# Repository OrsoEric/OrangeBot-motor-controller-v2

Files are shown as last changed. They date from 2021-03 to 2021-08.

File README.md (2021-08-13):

# OrangeBot-motor-controller-v2
Motor controller for OrangeBot Robot  
-VNH7040 Motor Driver  
-GD32VF103 Microcontroller  
-IG32E-05K Motor  

# Blog Entry  
https://orangebotpiwars2021.blogspot.com/2021/03/2021-03-20-orangebot-motor-controller.html

# Schematics  
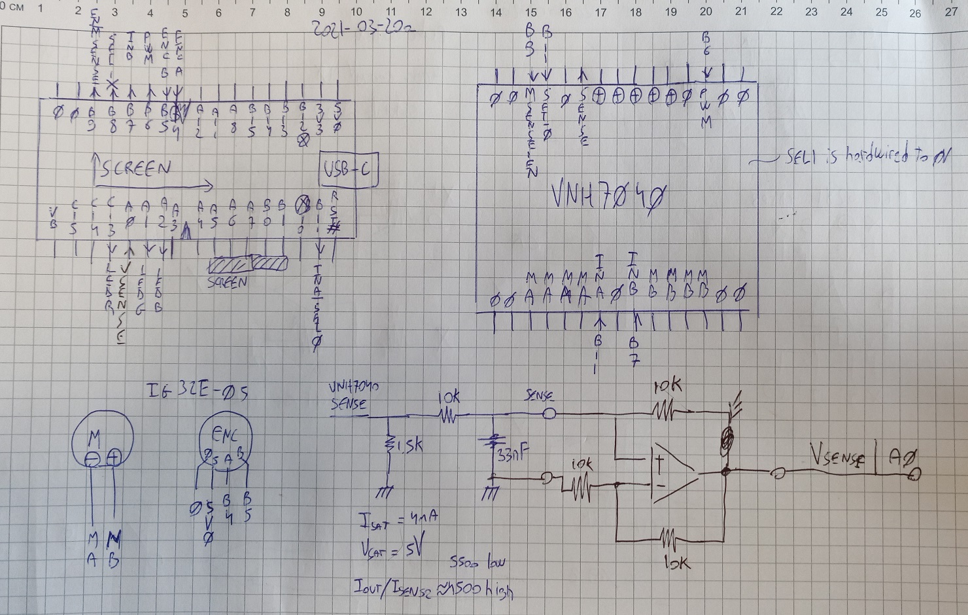
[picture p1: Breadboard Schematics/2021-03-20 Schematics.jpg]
Schematics
  

# Test bench  
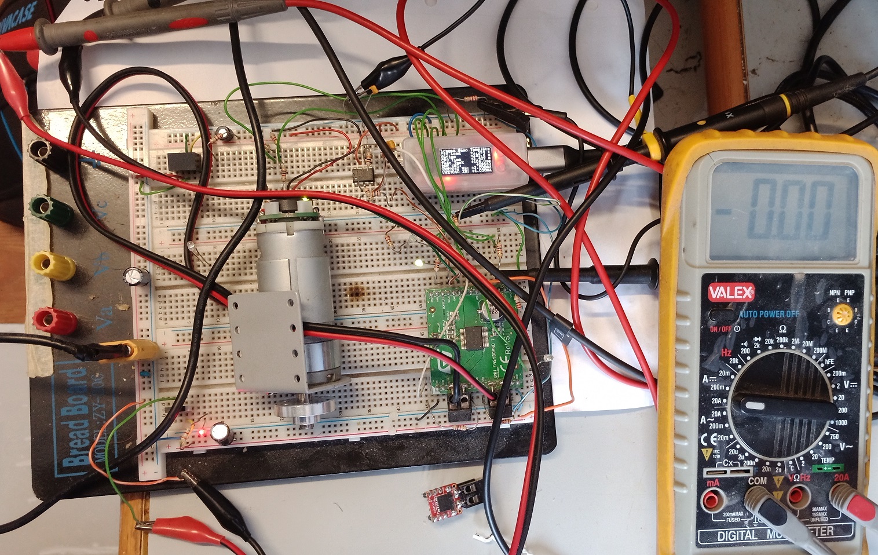
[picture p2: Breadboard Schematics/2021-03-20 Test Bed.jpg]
Test bench


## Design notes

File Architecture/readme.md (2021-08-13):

Features:  
- Use XT60 power connectors
- Daisy chain two power connectors
- RS485 communication bus using two 3.5mm Jack audio connectors
- Longan Nano GD32VF103 Risc-V 32b 108MHz microcontroller. Previous AT4809 lacked speed for the PIDs
- Quadrature Encoder with TTL levels
- LEDs for encoder activity and motor direction
- Overcurrent Protection, Reverse Voltage Protection and redundant VIN IIN monitor
 
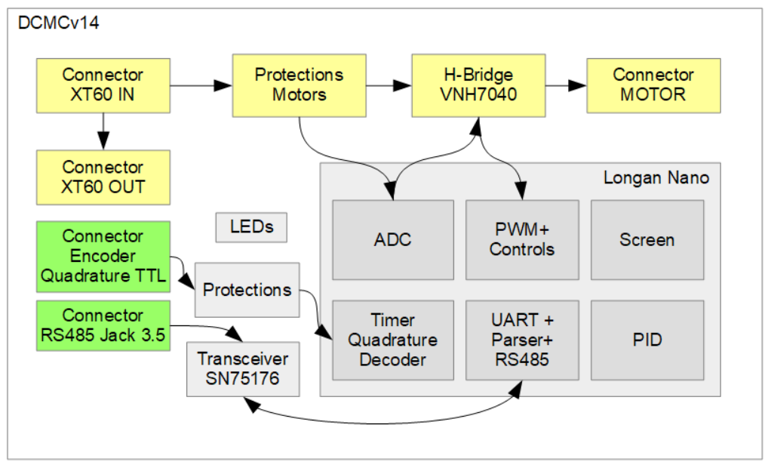
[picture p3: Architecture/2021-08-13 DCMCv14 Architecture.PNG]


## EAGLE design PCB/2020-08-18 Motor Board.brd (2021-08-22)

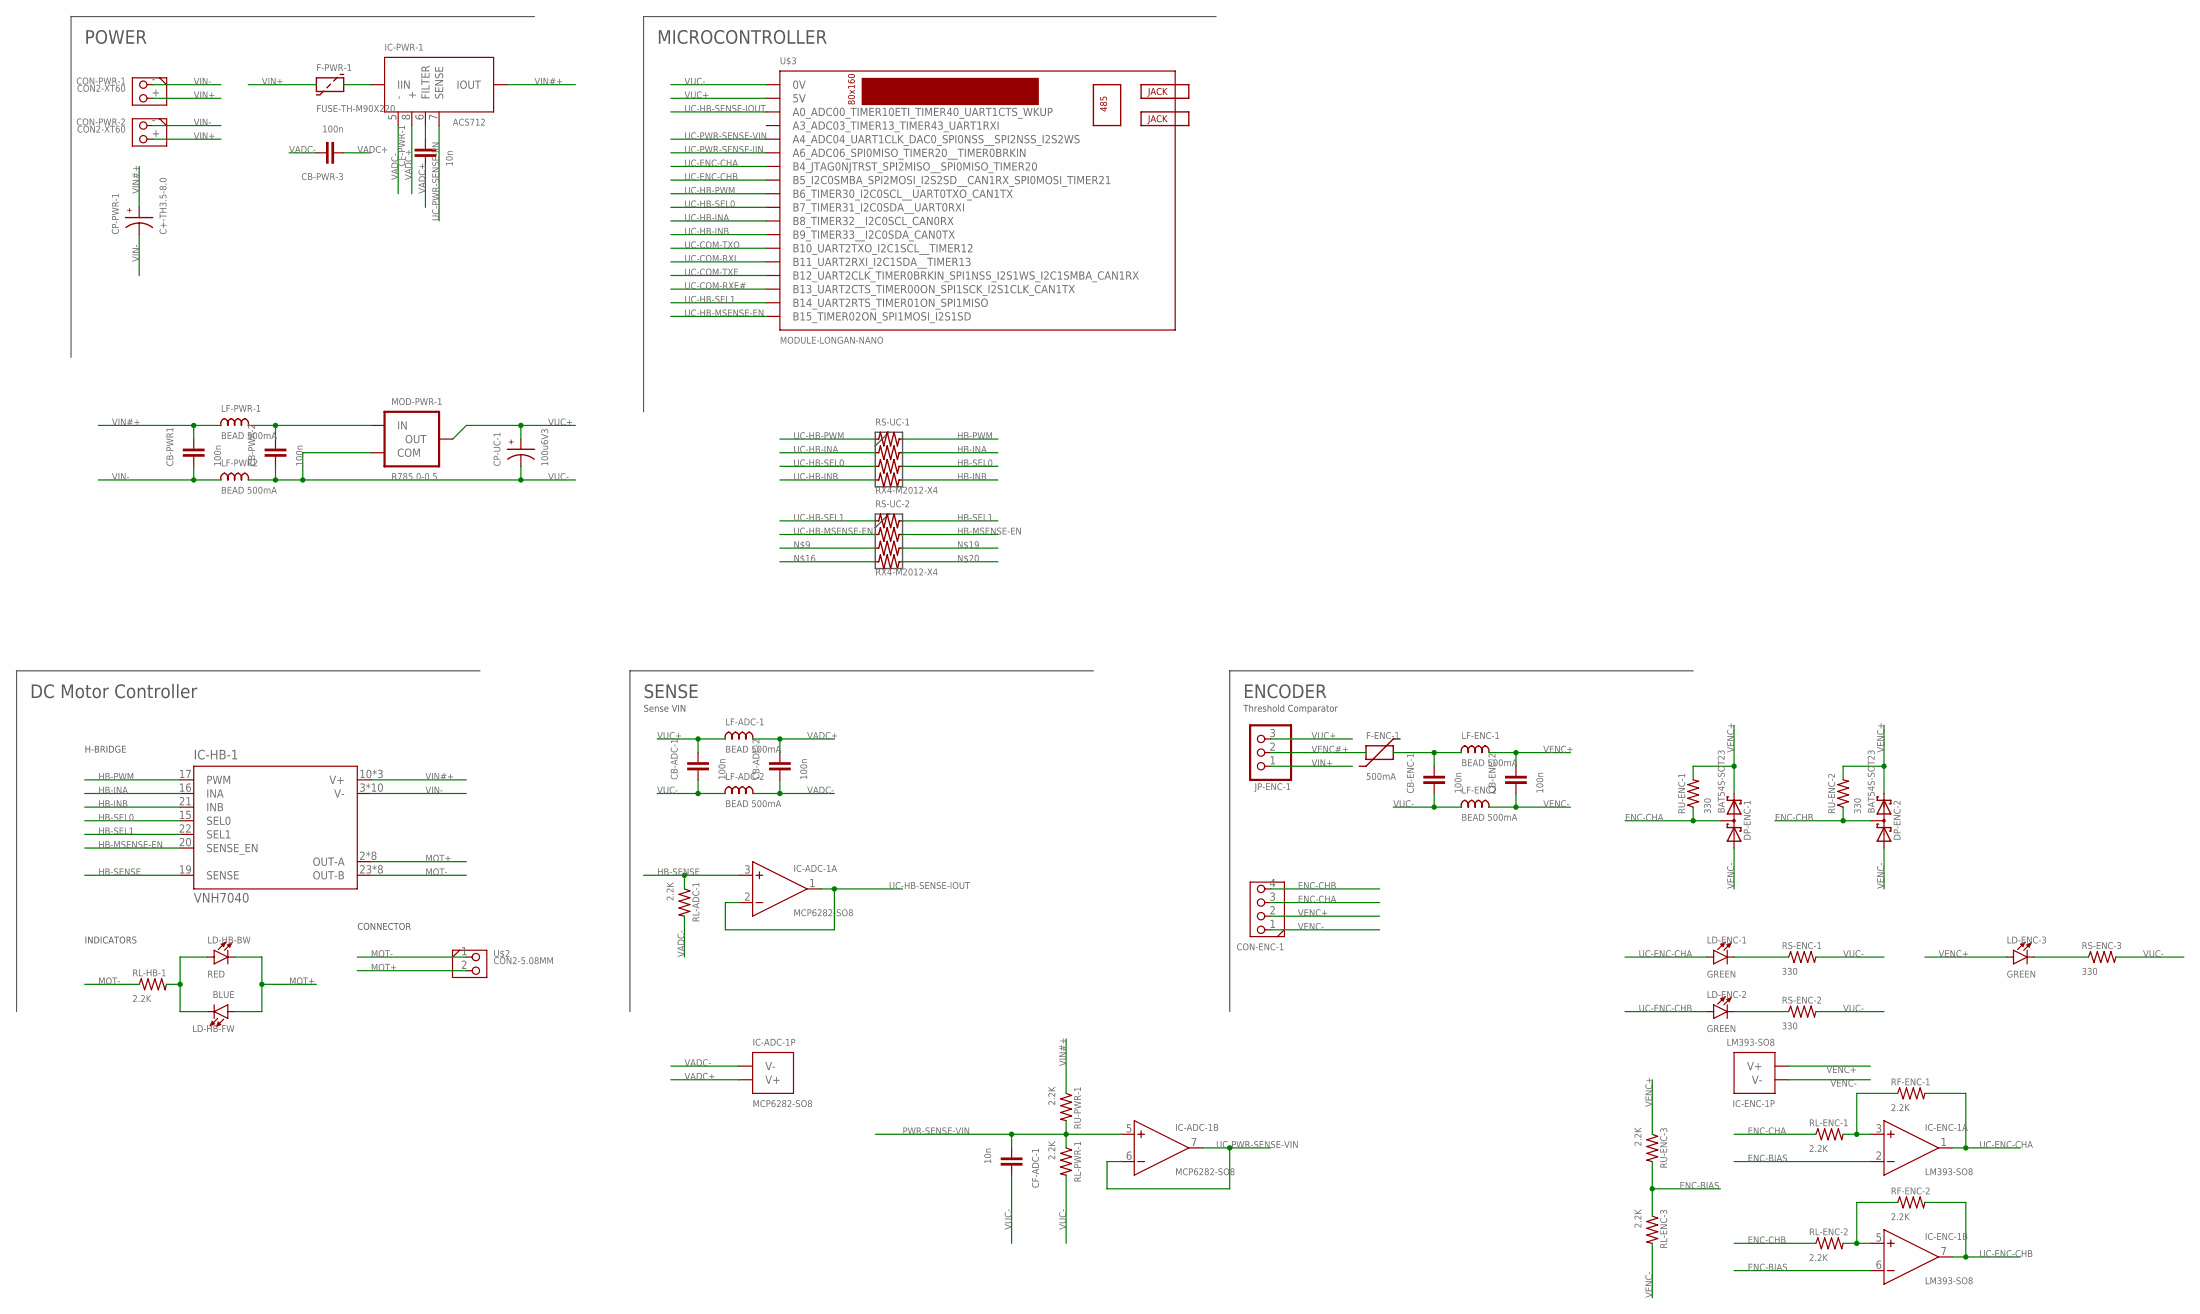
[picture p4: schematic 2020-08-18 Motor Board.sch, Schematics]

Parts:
CB-ADC-1, CB-ADC-2: 100n; SMD-M2012
CB-ENC-1, CB-ENC-2: 100n; SMD-M2012
CB-PWR1: 100n; SMD-M2012
CB-PWR-2, CB-PWR-3: 100n; SMD-M2012
CF-ADC-1: 10n; SMD-M2012
CF-PWR-1: 10n; SMD-M2012
CON-ENC-1: CON4
CON-PWR-1, CON-PWR-2: CON2-XT60; AMASS_XT60-M
CP-PWR-1: C+-TH3.5-8.0; TH-BARREL-3M5-8M0
CP-UC-1: 100u6V3; TH-BARREL-2M54-6M0
DP-ENC-1, DP-ENC-2: BAT54S-SOT23; SOT23
F-ENC-1: 500mA; SMD-M2012
F-PWR-1: FUSE-TH-M90X220; TH-BOX-MM9X22
IC-ADC-1: MCP6282-SO8; SO8
IC-ENC-1: LM393-SO8; SO8
IC-HB-1: VNH7040; SSO-36-TP
IC-PWR-1: ACS712; SO8
JP-ENC-1: PINHD-1X3; 1X03
LD-ENC-1, LD-ENC-2, LD-ENC-3: GREEN; SMD-M2012-POL
LD-HB-BW: RED; SMD-M2012-POL
LD-HB-FW: BLUE; SMD-M2012-POL
LF-ADC-1, LF-ADC-2: BEAD 500mA; SMD-M2012
LF-ENC2: BEAD 500mA; SMD-M2012
LF-ENC-1: BEAD 500mA; SMD-M2012
LF-PWR2: BEAD 500mA; SMD-M2012
LF-PWR-1: BEAD 500mA; SMD-M2012
MOD-PWR-1: R785.0-0.5; CUSTOM_SIP3_PIN
RF-ENC-1, RF-ENC-2: 2.2K; SMD-M2012
RL-ADC-1: 2.2K; SMD-M2012
RL-ENC-1, RL-ENC-2, RL-ENC-3: 2.2K; SMD-M2012
RL-HB-1: 2.2K; SMD-M2012
RL-PWR-1: 2.2K; SMD-M2012
RS-ENC-1, RS-ENC-2, RS-ENC-3: 330; SMD-M2012
RS-UC-1, RS-UC-2: RX4-M2012-X4; SMD-M2012-X4
RU-ENC-1, RU-ENC-2: 330; SMD-M2012
RU-ENC-3: 2.2K; SMD-M2012
RU-PWR-1: 2.2K; SMD-M2012
U$2: CON2-5.08MM; CON2-508
U$3: MODULE-LONGAN-NANO

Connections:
ENC-BIAS: IC-ENC-1.2 (-IN), IC-ENC-1.6 (-IN), RL-ENC-3.1, RU-ENC-3.2
ENC-CHA: CON-ENC-1.3, DP-ENC-1.3 (C1A2), RL-ENC-1.1, RU-ENC-1.1
ENC-CHB: CON-ENC-1.4, DP-ENC-2.3 (C1A2), RL-ENC-2.1, RU-ENC-2.1
HB-INA: IC-HB-1.16 (INA), RS-UC-1.2B
HB-INB: IC-HB-1.21 (INB), RS-UC-1.4B
HB-MSENSE-EN: IC-HB-1.20 (SENSE_EN), RS-UC-2.2B
HB-PWM: IC-HB-1.17 (PWM), RS-UC-1.1B
HB-SEL0: IC-HB-1.15 (SEL0), RS-UC-1.3B
HB-SEL1: IC-HB-1.22 (SEL1), RS-UC-2.1B
HB-SENSE: IC-ADC-1.3 (+IN), IC-HB-1.19 (SENSE), RL-ADC-1.1
MOT+: IC-HB-1.2 (OUT-A), IC-HB-1.8 (OUT-A), IC-HB-1.9 (OUT-A), IC-HB-1.11 (OUT-A), IC-HB-1.12 (OUT-A), IC-HB-1.13 (OUT-A), IC-HB-1.14 (OUT-A), IC-HB-1.PAD2 (OUT-A), LD-HB-BW.-, LD-HB-FW.+, U$2.2
MOT-: IC-HB-1.23 (OUT-B), IC-HB-1.24 (OUT-B), IC-HB-1.25 (OUT-B), IC-HB-1.26 (OUT-B), IC-HB-1.28 (OUT-B), IC-HB-1.29 (OUT-B), IC-HB-1.35 (OUT-B), IC-HB-1.PAD3 (OUT-B), RL-HB-1.1, U$2.1
unnamed: LD-HB-BW.+, LD-HB-FW.-, RL-HB-1.2
unnamed: CF-PWR-1.2, IC-PWR-1.6 (FILTER)
unnamed: F-PWR-1.2, IC-PWR-1.1 (IIN), IC-PWR-1.2 (IIN)
unnamed: IC-ENC-1.3 (+IN), RF-ENC-1.1, RL-ENC-1.2
unnamed: LD-ENC-2.-, RS-ENC-2.1
unnamed: IC-ENC-1.5 (+IN), RF-ENC-2.1, RL-ENC-2.2
unnamed: LD-ENC-1.-, RS-ENC-1.1
unnamed: CB-PWR-2.2, LF-PWR-1.2, MOD-PWR-1.VIN (IN)
unnamed: CB-ENC-1.2, F-ENC-1.2, LF-ENC-1.1
unnamed: LD-ENC-3.-, RS-ENC-3.1
PWR-SENSE-VIN: CF-ADC-1.1, IC-ADC-1.5 (+IN), RL-PWR-1.1, RU-PWR-1.2
UC-COM-RXE#: U$3.B13 (B13_UART2CTS_TIMER00ON_SPI1SCK_I2S1CLK_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)
UC-COM-RXI: U$3.B11 (B11_UART2RXI_I2C1SDA__TIMER13)
UC-COM-TXE: U$3.B12 (B12_UART2CLK_TIMER0BRKIN_SPI1NSS_I2S1WS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)
UC-COM-TXO: U$3.B10 (B10_UART2TXO_I2C1SCL__TIMER12)
UC-ENC-CHA: IC-ENC-1.1 (OUT), LD-ENC-1.+, RF-ENC-1.2, U$3.B4 (B4_JTAG0NJTRST_SPI2MISO__SPI0MISO_TIMER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)
UC-ENC-CHB: IC-ENC-1.7 (OUT), LD-ENC-2.+, RF-ENC-2.2, U$3.B5 (B5_I2C0SMBA_SPI2MOSI_I2S2SD__CAN1RX_SPI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)
UC-HB-INA: RS-UC-1.2A, U$3.B8 (B8_TIMER32__I2C0SCL_CAN0RX)
UC-HB-INB: RS-UC-1.4A, U$3.B9 (B9_TIMER33__I2C0SDA_CAN0TX)
UC-HB-MSENSE-EN: RS-UC-2.2A, U$3.B15 (B15_TIMER02ON_SPI1MOSI_I2S1SD)
UC-HB-PWM: RS-UC-1.1A, U$3.B6 (B6_TIMER30_I2C0SCL__UART0TXO_CAN1TX)
UC-HB-SEL0: RS-UC-1.3A, U$3.B7 (B7_TIMER31_I2C0SDA__UART0RXI)
UC-HB-SEL1: RS-UC-2.1A, U$3.B14 (B14_UART2RTS_TIMER01ON_SPI1MISO)
UC-HB-SENSE-IOUT: IC-ADC-1.1 (OUT), IC-ADC-1.2 (-IN), U$3.A0 (A0_ADC00_TIMER10ETI_TIMER40_UART1CTS_WK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)
UC-PWR-SENSE-IIN: IC-PWR-1.7 (SENSE), U$3.A6 (A6_ADC06_SPI0MISO_TIMER20__TIMER0BRKIN)
UC-PWR-SENSE-VIN: IC-ADC-1.6 (-IN), IC-ADC-1.7 (OUT), U$3.A4 (A4_ADC04_UART1CLK_DAC0_SPI0NSS__SPI2NSS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)
VADC+: CB-ADC-2.2, CB-PWR-3.1, CF-PWR-1.1, IC-ADC-1.8 (V+), IC-PWR-1.8 (+), LF-ADC-1.2
VADC-: CB-ADC-2.1, CB-PWR-3.2, IC-ADC-1.4 (V-), IC-PWR-1.5 (-), LF-ADC-2.2, RL-ADC-1.2
VENC#+: F-ENC-1.1, JP-ENC-1.2
VENC+: CB-ENC-2.2, CON-ENC-1.2, DP-ENC-1.2 (C2), DP-ENC-2.2 (C2), IC-ENC-1.8 (V+), LD-ENC-3.+, LF-ENC-1.2, RU-ENC-1.2, RU-ENC-2.2, RU-ENC-3.1
VENC-: CB-ENC-2.1, CON-ENC-1.1, DP-ENC-1.1 (A1), DP-ENC-2.1 (A1), IC-ENC-1.4 (V-), LF-ENC2.2, RL-ENC-3.2
VIN#+: CB-PWR1.2, CP-PWR-1.+, IC-HB-1.10 (V+), IC-HB-1.27 (V+), IC-HB-1.PAD1 (V+), IC-PWR-1.3 (IOUT), IC-PWR-1.4 (IOUT), LF-PWR-1.1, RU-PWR-1.1
VIN+: CON-PWR-1.+ (2), CON-PWR-2.+ (2), F-PWR-1.1, JP-ENC-1.1
VIN-: CB-PWR1.1, CON-PWR-1.- (1), CON-PWR-2.- (1), CP-PWR-1.-, IC-HB-1.3 (V-), IC-HB-1.4 (V-), IC-HB-1.5 (V-), IC-HB-1.6 (V-), IC-HB-1.7 (V-), IC-HB-1.30 (V-), IC-HB-1.31 (V-), IC-HB-1.32 (V-), IC-HB-1.33 (V-), IC-HB-1.34 (V-), LF-PWR2.1
VUC+: CB-ADC-1.2, CP-UC-1.+, JP-ENC-1.3, LF-ADC-1.1, MOD-PWR-1.OUT, U$3.5V
VUC-: CB-ADC-1.1, CB-ENC-1.1, CB-PWR-2.1, CF-ADC-1.2, CP-UC-1.-, LF-ADC-2.1, LF-ENC2.1, LF-PWR2.2, MOD-PWR-1.COM, RL-PWR-1.2, RS-ENC-1.2, RS-ENC-2.2, RS-ENC-3.2, U$3.0V

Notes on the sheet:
POWER
MICROCONTROLLER
DC Motor Controller
ENCODER
SENSE
H-BRIDGE
INDICATORS
CONNECTOR
Threshold Comparator
Sense VIN

Board: 2 copper layers, 54 parts (16 on the bottom side), 44 nets, no tracks yet.

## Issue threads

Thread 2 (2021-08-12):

DCMC - Schematics - Breadboard

OrsoEric, 2021-08-12:
VNH7040 and Longan Nano have been tested on a breadboard.

- IG32-05 DC Motor with encoder
- VNH7040 Evaluation Board
- Longan Nano GD32VF103 board with screen and USB-C programmer

OrsoEric, 2021-08-12:
Schematics
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

Closed 2021-08-12.

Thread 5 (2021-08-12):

DCMC - Firmware

OrsoEric, 2021-08-12:
Firmware for the DCMC (DC Motor Controller)

Breadboard Tests
- [ ] Longan Nano LCD
- [ ] Longan Nano Task Scheduler
- [ ] Longan nano ADC
- [ ] VNH7040 Open Loop PWM Ramp
- [ ] IG32-05 Encoder acquisition
- [ ] VNH7040 Closed Loop Position

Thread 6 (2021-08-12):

DCMC - PCB

OrsoEric, 2021-08-12:
Design of the PCB Printed Circuit Board for the DC Motor Controller v14

- [ ] Net Classes
- [ ] Design Rules
- [ ] Placement
- [ ] Routing
- [ ] Gerber

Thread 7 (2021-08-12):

DCMC - PCB - Placement

OrsoEric, 2021-08-12:
Define board size and derive initial placement of components on the board.

OrsoEric, 2021-08-12:
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

OrsoEric, 2021-08-22:
Specifications:
- Board Size: 60mm x 60mm
- Vertical mounting of Longan nano via daughter board. Includes 485 communications
- Square holes 4.5mm in a 50x50mm grid
- Vertical stacking of board by strategically soldering the XT60 in a daisy chain

Initial placement and initial result of auto-router

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

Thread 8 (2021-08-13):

DCMC - Change Repository Structure

OrsoEric, 2021-08-13:
This repository was originally meant to store the firmware for the breadboard test for the new PiWars motor controller.

Scope of the project has increased to make an high power DC motor controller compatible with the OrangeHat.

OrsoEric, 2021-08-13:
Updated repository structure to include breadboard and PCB sections.

Closed 2021-08-13.

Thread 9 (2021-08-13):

DCMC - Architecture

OrsoEric, 2021-08-13:
Architecture and features for the DCMC DC Motor Controller.

OrsoEric, 2021-08-13:
Features:
- Use XT60 power connectors
- Daisy chain two power connectors
- RS485 communication bus using two 3.5mm Jack audio connectors
- Longan Nano GD32VF103 Risc-V 32b 108MHz microcontroller. Previous AT4809 lacked speed for the PIDs
- Quadrature Encoder with TTL levels
- LEDs for encoder activity and motor direction
- Overcurrent Protection, Reverse Voltage Protection and redundant VIN IIN monitor

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

Closed 2021-08-13.

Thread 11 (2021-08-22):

DCMC - Schematics - Power

OrsoEric, 2021-08-22:
Specifications:
- Two XT60 power connectors to allow daisy chain both with cables and vertically.
- Buck module to generate 5V for the logic
- Extensive power filters
- Independent measure of IIN using a current sensor. It is redundant since VNH7040 has integrated current sensing. It's meant for validation.

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

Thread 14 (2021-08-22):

DCMC - Schematics - Encoder

OrsoEric, 2021-08-22:
Specifications:
- Quadrature encoder, single ended
- Optional pull-up resistors for open drain encoders
- Jumper to select encoder supply between 5V/VIN
- PTC to protect encoder supply from short circuit on encoder
- High speed rail to rail comparators with hysteresis on channels
- Power filter

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

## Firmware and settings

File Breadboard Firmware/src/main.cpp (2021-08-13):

/****************************************************************************
**	OrangeBot Project
*****************************************************************************
**        /
**       /
**      /
** ______ \
**         \
**          \
*****************************************************************************
**	Quadrature Encoder
*****************************************************************************
**  Activate Timer 2 in quadrature mode
**  Count a quadrature encoder connected to PB4 and PB5
**  Display the encoder count on screen
**  Repository:
**  https://github.com/OrsoEric/OrangeBot-motor-controller-v2
**      2021-03-20
**  Remove uC temperature. Add ADC CH0, motor Vsense
****************************************************************************/

/****************************************************************************
**	INCLUDES
****************************************************************************/

//C++ std random number generators
#include <random>
//Longan Nano HAL
#include <gd32vf103.h>
//LED class
#include "longan_nano_led.hpp"
//Time class
#include "longan_nano_chrono.hpp"
//Scheduler class
#include "longan_nano_scheduler.hpp"
//Higher level abstraction layer to base Display Class. Provides character sprites and print methods with color
#include "longan_nano_screen.hpp"
//Driver for the VNH7040 H-Bridge
#include "longan_nano_vnh7040.hpp"
//Old 16b PID controller
#include "pid_s16.h"

/****************************************************************************
**	NAMESPACES
****************************************************************************/

/****************************************************************************
**	DEFINES
****************************************************************************/

//forever
#define EVER (;;)

/****************************************************************************
**	MACROS
****************************************************************************/

/****************************************************************************
**	ENUM
****************************************************************************/

//Configurations
typedef enum _Config
{
    SCHEDULER_UNIT      = Longan_nano::Chrono::Unit::microseconds,
    //Microseconds between calls of the screen update method. User decides how much CPU to allocate to the screen by tuning this time.
    //Longer time will mean fewer sprites rendered per second, but no matter what, the screen class will not crash as only the most recent sprite is drawn
    SCREEN_US           = 100,
    //HMI UPDATE
    HMI_US              = 100000,
    //Microseconds between led toggles
    RED_LED_BLINK_US    = 250000,
    //Microseconds between paint of colored square
    PAINT_TASK_US       = 300000,

    VNH7040_TASK_US     = 1000,

    SCREEN_TASK_INDEX   = 0,
    HMI_TASK_INDEX      = 1,
    RED_LED_TASK_INDEX  = 2,
    PAINT_TASK_INDEX    = 3,
    VNH7040_TASK_INDEX  = 4,
    PAINT_START_HEIGHT  = 6,
} Config;

/****************************************************************************
**	STRUCT
****************************************************************************/

typedef struct _Scheduler
{
    bool f_screen       : 1;
    bool f_demo         : 1;
    bool f_overrun      : 1;
} Scheduler;

/****************************************************************************
**  PROTOTYPES
****************************************************************************/

//Initialize
extern bool init_enc( void );

extern bool init_adc_temp(void);

extern bool test_vnh7040( void );

/****************************************************************************
**  GLOBAL VARIABILES
****************************************************************************/

volatile bool g_rtc_flag = false;

//C++ Standard Random Number Generator
std::default_random_engine g_rng_engine;
std::uniform_int_distribution<uint8_t> g_rng_color( 0, Longan_nano::Screen::Config::PALETTE_SIZE -1 );
//Scheduler for the tasks
Scheduler g_scheduler = { 0 };
//VNH7040 Motor controller
Longan_nano::VNH7040 g_vnh7040;
//PID controller
int_fast32_t gs32_vnh7040_command;
int_fast32_t gs32_encoder_feedback;
bool gu1_pid_error = false;

//Debug: use old controller for sanity check
Orangebot::Pid_s16 gcl_pid16_controller;

/****************************************************************************
**	FUNCTIONS
****************************************************************************/

/****************************************************************************
**	@brief main
**	main | void
****************************************************************************/
//! @return int |
//! @details Entry point of program
/***************************************************************************/

int main( void )
{
    //----------------------------------------------------------------
    //	VARS
    //----------------------------------------------------------------

    //Task scheduler. Initialize with fast tick for the screen driver
    Longan_nano::Scheduler g_scheduler = Longan_nano::Scheduler( Config::SCREEN_US, (Longan_nano::Chrono::Unit)Config::SCHEDULER_UNIT );
    //Display Driver
    Longan_nano::Screen g_screen;

    bool f_ret = false;

    //----------------------------------------------------------------
    //	INIT
    //----------------------------------------------------------------

    //Initialize LEDs
    Longan_nano::Leds::init();
    Longan_nano::Leds::set_color( Longan_nano::Leds::Color::BLACK );
    //Initialize scheduler
    f_ret |= g_scheduler.set_prescaler( Config::HMI_TASK_INDEX, Config::HMI_US /Config::SCREEN_US );
    f_ret |= g_scheduler.set_prescaler( Config::RED_LED_TASK_INDEX, Config::RED_LED_BLINK_US /Config::SCREEN_US );
    //f_ret |= g_scheduler.set_prescaler( Config::PAINT_TASK_INDEX, Config::PAINT_TASK_US /Config::SCREEN_US );
    f_ret |= g_scheduler.set_prescaler( Config::VNH7040_TASK_INDEX, Config::VNH7040_TASK_US /Config::SCREEN_US );
    //Initialize the Display
    g_screen.init();

    //Initialize Timer2 as Quadrature encoder decoder
    init_enc();
	//Initialize ADC
	init_adc_temp();
    //Initialize VNH7040
    f_ret = g_vnh7040.init();
    //PID Initialization
    
   	gcl_pid16_controller.gain_kp() = +12800;
	gcl_pid16_controller.gain_ki() = +100;
	gcl_pid16_controller.gain_kd() = +0;
	gcl_pid16_controller.set_limit_cmd( -10000, +10000 );
    
    //Error state
    //gu1_pid_error = !gcl_pid_controller.is_ready();
    gu1_pid_error = false;

    //----------------------------------------------------------------
    //	ERROR HANDLER
    //----------------------------------------------------------------

    if (f_ret == true)
    {
        g_screen.clear( Longan_nano::Screen::Color::RED );
        g_screen.print( 0, 0, "ERR: Init Failed", Longan_nano::Screen::Color::RED, Longan_nano::Screen::Color::BLACK );
        for EVER
        {
            //Update the screen
            g_screen.update();
        }
    }

    uint8_t task_index;

    //----------------------------------------------------------------
    //	BODY
    //----------------------------------------------------------------

    for EVER
    {
        //----------------------------------------------------------------
        //  Scheduler
        //----------------------------------------------------------------
        //  Hardwired scheduler to release tasks
        //  Thanks to the Longan Nano SysTick timer there is no need to use peripherals for timekeeping

        //Run the scheduler
        int8_t num_tasks = g_scheduler.update();
        //if: scheduling error
        if (num_tasks < 0)
        {
            g_screen.clear( Longan_nano::Screen::Color::LRED );
            g_screen.print( 0, 0, "ERR: Scheduler Error", Longan_nano::Screen::Color::LRED, Longan_nano::Screen::Color::BLACK );
        }

        //----------------------------------------------------------------
        //  Screen Driver
        //----------------------------------------------------------------

        //Set task index
        task_index = Config::SCREEN_TASK_INDEX;
        //if: task is scheduled for execution
        if (g_scheduler.is_task_scheduled( task_index ) == true)
        {
            //Task is running
            g_scheduler.run( task_index );
            
            //Update the screen
            g_screen.update();
            
            //Task is done running
            g_scheduler.done( task_index );
        }

        //----------------------------------------------------------------
        //  HMI Update
        //----------------------------------------------------------------

        //Set task index
        task_index = Config::HMI_TASK_INDEX;
        //if: task is scheduled for execution
        if (g_scheduler.is_task_scheduled( task_index )  == true)
        {
            //Task is running
            g_scheduler.run( task_index );
            
            //----------------------------------------------------------------
            //  Header
            //----------------------------------------------------------------
    
            g_screen.print( 0, 0, "Longan Nano Template" );

            //----------------------------------------------------------------
            //  CPU Load
            //----------------------------------------------------------------
    
            /*
            g_screen.print( 1, 0, "CPU Load" );
            //Use top of 100000 to get enough decimals. To print in the right format witn 100000->100.0% ENG exponent is -3 (TOP 100000 /10^ENG_EXP -3 = 100)
            g_screen.set_format( 8, Longan_nano::Screen::Format_align::ADJ_RIGHT, Longan_nano::Screen::Format_format::ENG, -3 );
            //Get CPU load with 100000 = 100.0%
            int cpu_load = g_scheduler.get_cpu_load( 100000 );
            g_screen.print( 1, 18, cpu_load );
            g_screen.print( 1, 19, '%' );
            */
            
            //----------------------------------------------------------------
            //  Uptime and CPU Time
            //----------------------------------------------------------------
            int tmp;
            //Since the time is measured in millisecond exponent is 10^-3
            g_screen.set_format( 8, Longan_nano::Screen::Format_align::ADJ_RIGHT, Longan_nano::Screen::Format_format::ENG, -3 );
            
            if (gu1_pid_error == true)
            {
                g_screen.print( 2, 0, "PID ERROR" );
            }
            else
            {
                g_screen.print( 2, 0, "PID OK" );
            }
            /*
            g_screen.print( 2, 0, "Uptime" );
            tmp = g_scheduler.get_uptime( Longan_nano::Chrono::Unit::milliseconds );
            g_screen.print( 2, 18, tmp );
            g_screen.print( 2, 19, 's' );
            */
            
            /*
            g_screen.print( 3, 0, "CPU Time" );
            tmp = g_scheduler.get_cpu_time( Longan_nano::Chrono::Unit::milliseconds );
            g_screen.print( 3, 18, tmp );
            g_screen.print( 3, 19, 's' );
            */

            g_screen.set_format( 8, Longan_nano::Screen::Format_align::ADJ_RIGHT, Longan_nano::Screen::Format_format::NUM );
            g_screen.print( 3, 0, "VNH7040" );
            g_screen.print( 3, 19, gs32_vnh7040_command );

            //----------------------------------------------------------------
            //  Execution time of fast task
            //---------------------------------------------------------------- 

            g_screen.print( 4, 0, "Fast Task" );
            tmp = g_scheduler.get_fast_task_avg_time();
            //The scheduler is using microseconds as time unit in the configuration
            g_screen.set_format( 8, Longan_nano::Screen::Format_align::ADJ_RIGHT, Longan_nano::Screen::Format_format::ENG, -6 );
            g_screen.print( 4, 18, tmp );
            g_screen.print( 4, 19, 's' );            

            //----------------------------------------------------------------
            //  ENC Profiling
            //---------------------------------------------------------------- 
            
            //Get the count of the timer
            tmp = gs32_encoder_feedback;
            g_screen.set_format( 8, Longan_nano::Screen::Format_align::ADJ_RIGHT, Longan_nano::Screen::Format_format::NUM );
            g_screen.print( 5, 0, "ENC CNT:" );
            g_screen.print( 5, 19, tmp );

            //----------------------------------------------------------------
            //  ADC Acquisition
            //---------------------------------------------------------------- 
	
            //Fetch and process temperature in celsius m[°c] 
            //int temperature = (1430000 - ADC_IDATA0(ADC0)*(3300000/4096)) / 4300 + 25000;
            int vnh7040_sense = ADC_IDATA0(ADC0) *3300 /4096;
            //Convert from VNH7040 sense voltage to motor current
            int vnh7040_current = vnh7040_sense *888/1000;
            //Fetch and process the reference in volts m[V]
            int vref_value = ADC_IDATA1(ADC0) *3300 /4096;
            adc_software_trigger_enable(ADC0, ADC_INSERTED_CHANNEL);
            //Compensate for the 'm' suffix, which is just used to have more digits
			g_screen.set_format( 8, Longan_nano::Screen::Format_align::ADJ_RIGHT, Longan_nano::Screen::Format_format::ENG, -3 );
            //Show temperature
			g_screen.print( 6, 0, "VNH7040 Vs:" );
            g_screen.print( 6, 18, vnh7040_sense );
			g_screen.print( 6, 19, 'V' );
            //Show voltage
            g_screen.print( 7, 0, "VNH7040 IM:" );
            g_screen.print( 7, 18, vnh7040_current );
            g_screen.print( 7, 19, 'A' );

            //Task is done running
            g_scheduler.done( task_index );
        }

        //----------------------------------------------------------------
        //  RED LED
        //----------------------------------------------------------------

        //Set task index
        task_index = Config::RED_LED_TASK_INDEX;
        //if: task is scheduled for execution
        if (g_scheduler.is_task_scheduled( task_index )  == true)
        {
            //Task is running
            g_scheduler.run( task_index );
        
            Longan_nano::Leds::toggle( Longan_nano::Leds::Color::RED );

            //Task is done running
            g_scheduler.done( task_index );
        }

        //----------------------------------------------------------------
        //  PAINT
        //----------------------------------------------------------------

        //Set task index
        task_index = Config::PAINT_TASK_INDEX;
        //if: task is scheduled for execution
        if (g_scheduler.is_task_scheduled( task_index )  == true)
        {
            //Task is running
            g_scheduler.run( task_index );
            
            //Roll a color
            Longan_nano::Screen::Color color_tmp = (Longan_nano::Screen::Color)g_rng_color(g_rng_engine);
            //Paint a colored square on screen
            g_screen.paint( Config::PAINT_START_HEIGHT, 0, Longan_nano::Screen::FRAME_BUFFER_HEIGHT -1, Longan_nano::Screen::FRAME_BUFFER_WIDTH -1, color_tmp );

            //Task is done running
            g_scheduler.done( task_index );
        }

        //----------------------------------------------------------------
        //  VNH7040
        //----------------------------------------------------------------

        //Set task index
        task_index = Config::VNH7040_TASK_INDEX;
        //if: task is scheduled for execution
        if (g_scheduler.is_task_scheduled( task_index ) == true)
        {
            //Task is running
            g_scheduler.run( task_index );
            
            //Feed a PWMramp
            //test_vnh7040();
            
            //PID16 controller
            gs32_encoder_feedback = TIMER_CNT( TIMER2 );
            gs32_vnh7040_command = gcl_pid16_controller.exe( int32_t(32000), gs32_encoder_feedback  );
            //true=PID is in protection mode
            gu1_pid_error = gcl_pid16_controller.get_pid_status();
            if (gu1_pid_error == true)
            {
                gs32_vnh7040_command = 0;
                g_vnh7040.set_speed( 0 );
            }
            else
            {
                g_vnh7040.set_speed( gs32_vnh7040_command );
            }
            
            //Task is done running
            g_scheduler.done( task_index );
        }

        //----------------------------------------------------------------
        //  BUSY Wait
        //----------------------------------------------------------------
        //  Without wait, CPU load is 81% since the main is looping very fast when counting the scheduler
        //  Adding a busy wait lowers the CPU load to 12%
        //  The actual use of the task is about 1.1%, including the screen driver
        //  Scheduler execution should not be counted inside the CPU time as it only influences the precision of the flags
        //  The application can go into sleep for a time here instead of waiting

        //Longan_nano::Chrono::delay( Longan_nano::Chrono::Unit::microseconds, 1 );

    } //End forever

    //----------------------------------------------------------------
    //	RETURN
    //----------------------------------------------------------------

    return 0;
}	//end function: main


//Initialize timer2 as dual channel quadrature decoder
bool init_enc( void )
{
    //Clock the timer
    rcu_periph_clock_enable(RCU_TIMER2);
    //Clear initialization
    timer_deinit( TIMER2 );

    //Initialize timer GPIO
    rcu_periph_clock_enable( RCU_GPIOB );
    rcu_periph_clock_enable( RCU_AF );
    //TIMER2:PB4:CH0 TIMER2:PB5:CH1
    gpio_init( GPIOB, GPIO_MODE_IN_FLOATING, GPIO_OSPEED_50MHZ, GPIO_PIN_4 );
    gpio_init( GPIOB, GPIO_MODE_IN_FLOATING, GPIO_OSPEED_50MHZ, GPIO_PIN_5 );
    gpio_pin_remap_config( GPIO_TIMER2_PARTIAL_REMAP, ENABLE );

    timer_auto_reload_shadow_enable(TIMER2);
    timer_parameter_struct timer_initpara;
    timer_struct_para_init(&timer_initpara);
    timer_initpara.prescaler         = 0;                   //Prescaler for the counter.
    timer_initpara.alignedmode       = TIMER_COUNTER_EDGE;  //Alignment specified by DIR bit
    timer_initpara.counterdirection  = TIMER_COUNTER_UP;    //Used in counter and encoder mode. Will be owerwritten by the quadrature mode
    timer_initpara.period            = UINT16_MAX;          //Counter Auto Reload. Value loaded for underflow or overflow
    timer_initpara.clockdivision     = TIMER_CKDIV_DIV1;    //Dead time and sampling clock DTS prescaler
    timer_init(TIMER2, &timer_initpara);
    
    //Quadrature encoder with double edge sensitivity
    timer_quadrature_decoder_mode_config( TIMER2, TIMER_ENCODER_MODE2, TIMER_IC_POLARITY_RISING, TIMER_IC_POLARITY_RISING );

    //timer_interrupt_flag_clear(TIMER2,TIMER_INT_FLAG_CH0);
    //timer_interrupt_enable(TIMER2,TIMER_INT_CH0);
    //Timer works in excess 0x8000
    TIMER_CNT( TIMER2 ) = uint16_t( 0x8000 );
    //timer_counter_value_config( TIMER2, 0x8000 );
    timer_enable(TIMER2);    
    
    return false;
}

bool init_adc_temp(void)
{

    //Clock GPIO
    rcu_periph_clock_enable(RCU_GPIOA);
    //Configure PA0 as analog input
    gpio_init( GPIOA, GPIO_MODE_AIN, GPIO_OSPEED_50MHZ, GPIO_PIN_0 );
    //Clock the ADC
    rcu_periph_clock_enable(RCU_ADC0);
    /* config ADC clock */
    rcu_adc_clock_config(RCU_CKADC_CKAPB2_DIV4);
    /* reset ADC */
    adc_deinit(ADC0);
    /* ADC mode config */
    adc_mode_config(ADC_MODE_FREE);
    /* ADC scan function enable */
    adc_special_function_config(ADC0, ADC_SCAN_MODE, ENABLE);
    /* ADC data alignment config */
    adc_data_alignment_config(ADC0, ADC_DATAALIGN_RIGHT);
    /* ADC temperature and Vrefint enable */
    adc_tempsensor_vrefint_enable();
    
    /* ADC channel length config */
    adc_channel_length_config(ADC0, ADC_INSERTED_CHANNEL, 2);
    /* ADC Channel 0, connected to VNH7040 VSense */
    adc_inserted_channel_config(ADC0, 0, ADC_CHANNEL_0, ADC_SAMPLETIME_239POINT5);
    /* ADC internal reference voltage channel config */
    adc_inserted_channel_config(ADC0, 1, ADC_CHANNEL_17, ADC_SAMPLETIME_239POINT5);

    /* ADC trigger config */
    adc_external_trigger_source_config(ADC0, ADC_INSERTED_CHANNEL, ADC0_1_EXTTRIG_INSERTED_NONE);
    adc_external_trigger_config(ADC0, ADC_INSERTED_CHANNEL, ENABLE);
    
    /* enable ADC interface */
    adc_enable(ADC0);
    Longan_nano::Chrono::delay( Longan_nano::Chrono::Unit::milliseconds, 1 );
    /* ADC calibration and reset calibration */
    adc_calibration_enable(ADC0);
	//Trigger f
	//adc_software_trigger_enable(ADC0, ADC_INSERTED_CHANNEL);
	
	return false;
}

/***************************************************************************/
//! @brief Private method
//! \n test_vnh7040 | void |
/***************************************************************************/
// @param
//! @return bool | false = OK | true = FAIL |
//! @details
//! \n Method
/***************************************************************************/
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

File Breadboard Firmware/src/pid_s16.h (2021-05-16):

/**********************************************************************************
**	ENVIROMENT VARIABILE
**********************************************************************************/

#ifndef PID_S16_H_
	#define PID_S16_H_

/**********************************************************************************
**	GLOBAL INCLUDES
**********************************************************************************/

/**********************************************************************************
**	DEFINES
**********************************************************************************/

/**********************************************************************************
**	MACROS
**********************************************************************************/

/**********************************************************************************
**	NAMESPACE
**********************************************************************************/

//! @namespace OrangeBot
namespace Orangebot
{

/**********************************************************************************
**	TYPEDEFS
**********************************************************************************/

typedef enum _Pid_s16_config
{
	//Limits of S16. Limits are symmetrical for this class
	MAX_S16					= INT16_MAX,
	MIN_S16					= -32767,
	//Floating point position of the PID gain parameters
	GAIN_FP					= 8,
	//threshold expressed in (MAX/MIN)/2^n upon which the saturation threshold counter is increased
	SLEW_RATE_LIMIT			= 3,
	//Parameters for the Error low pass filter
	LP_ERR_GAIN				= 7,	//Gain for the low pass error estimation. Valid values are from 1 to (1<<PID_ERR_FP).
	LP_ERR_FP				= 3,	//Fixed point position for the low pass error estimation (1<<PID_ERR_FP)
	//Parameters for the Slew Rate low pass filter
	LP_SLEW_RATE_GAIN		= 7,
	LP_SLEW_RATE_FP			= 3,
	//Parameters for the two slope error gain
	TWO_SLOPE_INPUT_TH		= 16,
	TWO_SLOPE_OUTPUT_TH		= 128,
	TWO_SLOPE_GAIN_FP		= 0
} Pid_s16_config;

/**********************************************************************************
**	PROTOTYPE: STRUCTURES
**********************************************************************************/

/**********************************************************************************
**	PROTOTYPE: GLOBAL VARIABILES
**********************************************************************************/

/**********************************************************************************
**	PROTOTYPE: CLASS
**********************************************************************************/

/************************************************************************************/
//! @class 		Dummy
/************************************************************************************/
//!	@author		Orso Eric
//! @version	2020-01-28
//! @date		2019-11-08
//! @brief		PID
//! @details
//!	Advanced PID Library \n
//! FEATURES:	\n
//!		Command Saturation	\n
//! Detect when command is saturated \n
//! This inibiths the integrator from growing, improving response time \n
//! This allow a detection of PID unlock when the command is saturated for too long, meaning the PID can't keep up \n
//!		Error report	\n
//!
//! @pre		No prerequisites
//! @bug		None
//! @warning	No warnings
//! @copyright	License ?
//! @todo		todo list
/************************************************************************************/

class Pid_s16
{
	//Visible to all
	public:
		//--------------------------------------------------------------------------
		//	CONSTRUCTORS
		//--------------------------------------------------------------------------

		//! Default constructor
		Pid_s16( void );

		//--------------------------------------------------------------------------
		//	DESTRUCTORS
		//--------------------------------------------------------------------------

		//!Default destructor
		~Pid_s16( void );

		//--------------------------------------------------------------------------
		//	OPERATORS
		//--------------------------------------------------------------------------

		//--------------------------------------------------------------------------
		//	SETTERS
		//--------------------------------------------------------------------------

		//Set command limits
		bool set_limit_cmd( int16_t min, int16_t max );

		//--------------------------------------------------------------------------
		//	GETTERS
		//--------------------------------------------------------------------------

		//PID Status. false = OK | true = protection
		bool get_pid_status( void );
		//Error committed by the PID
		int16_t get_err( void );
		//Slew rate of the generated command. Give an indication of how hard a time the PID is having keeping a lock
		int16_t get_slew_rate( void );

		//--------------------------------------------------------------------------
		//	REFERENCES
		//--------------------------------------------------------------------------

		//PID limits
		int16_t &limit_cmd_max( void );
		int16_t &limit_cmd_min( void );
		uint16_t &limit_sat_th( void );

		//Set PID gain parameters
		int16_t &gain_kp( void );
		int16_t &gain_kd( void );
		int16_t &gain_ki( void );

		//--------------------------------------------------------------------------
		//	TESTERS
		//--------------------------------------------------------------------------

		//--------------------------------------------------------------------------
		//	PUBLIC METHODS
		//--------------------------------------------------------------------------

		//Execute a step of the PID controller. RET_ERR mean that the PID is now unlocked
		int16_t exe( int16_t reference, int16_t feedback );
		//Overload to allow for 32b inputs and 32b feedback signals. Error must still be 16b for the PID to operate as intended. EG. this allows to subtract the absolute position offset.
		int16_t exe( int32_t reference, int32_t feedback );
		//Reset the PID
		void reset( void );

		//--------------------------------------------------------------------------
		//	PUBLIC STATIC METHODS
		//--------------------------------------------------------------------------

		//--------------------------------------------------------------------------
		//	PUBLIC VARS
		//--------------------------------------------------------------------------

	//Visible to derived classes
	protected:
		//--------------------------------------------------------------------------
		//	PROTECTED METHODS
		//--------------------------------------------------------------------------

		//--------------------------------------------------------------------------
		//	PROTECTED VARS
		//--------------------------------------------------------------------------

	//Visible only inside the class
	private:
		//--------------------------------------------------------------------------
		//	PRIVATE METHODS
		//--------------------------------------------------------------------------

		//Initialize class vars
		void init( void );
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

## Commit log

2021-03-20 VNH7040: Operational | Encoder: Operational |
2021-03-20 2021-03-20 Acquisition of VNH7040 Current Sense pin
2021-03-20 2021-03-20 Schematics
2021-05-16 fixes 16bit PID. Now motor is closed in position
    [main.cpp, pid_s16.h]
2021-08-13 adds initial placement for PCB schematics and board.
    [2020-08-18 Motor Board.brd, 2020-08-18 Motor Board.sch]
2021-08-22 updates schematics, dimensions and placement.
    [2020-08-18 Motor Board.brd, 2020-08-18 Motor Board.sch]
